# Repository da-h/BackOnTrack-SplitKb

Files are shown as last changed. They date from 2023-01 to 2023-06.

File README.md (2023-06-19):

<h3 align="center">
    <br/>
    <br/><br/>
    Custom Split-Keyboard with 44 keys, 2 trackpads, 2 trackpad-buttons, per-key LED, underglow LED. Supports <a href="https://qmk.fm/">QMK Firmware</a>.
</h3>

<p align="center"> Steps: <a href="#setup">Manufacture</a>, <a href="#installation">Install</a>, <a href="#flashing">Flash</a>, <a href="#assemble">Assemble</a>
</p>

pcb

# Manufacture
(coming soon)

# Install
(coming soon)

# Flash
(coming soon)

# Assemble
(coming soon)

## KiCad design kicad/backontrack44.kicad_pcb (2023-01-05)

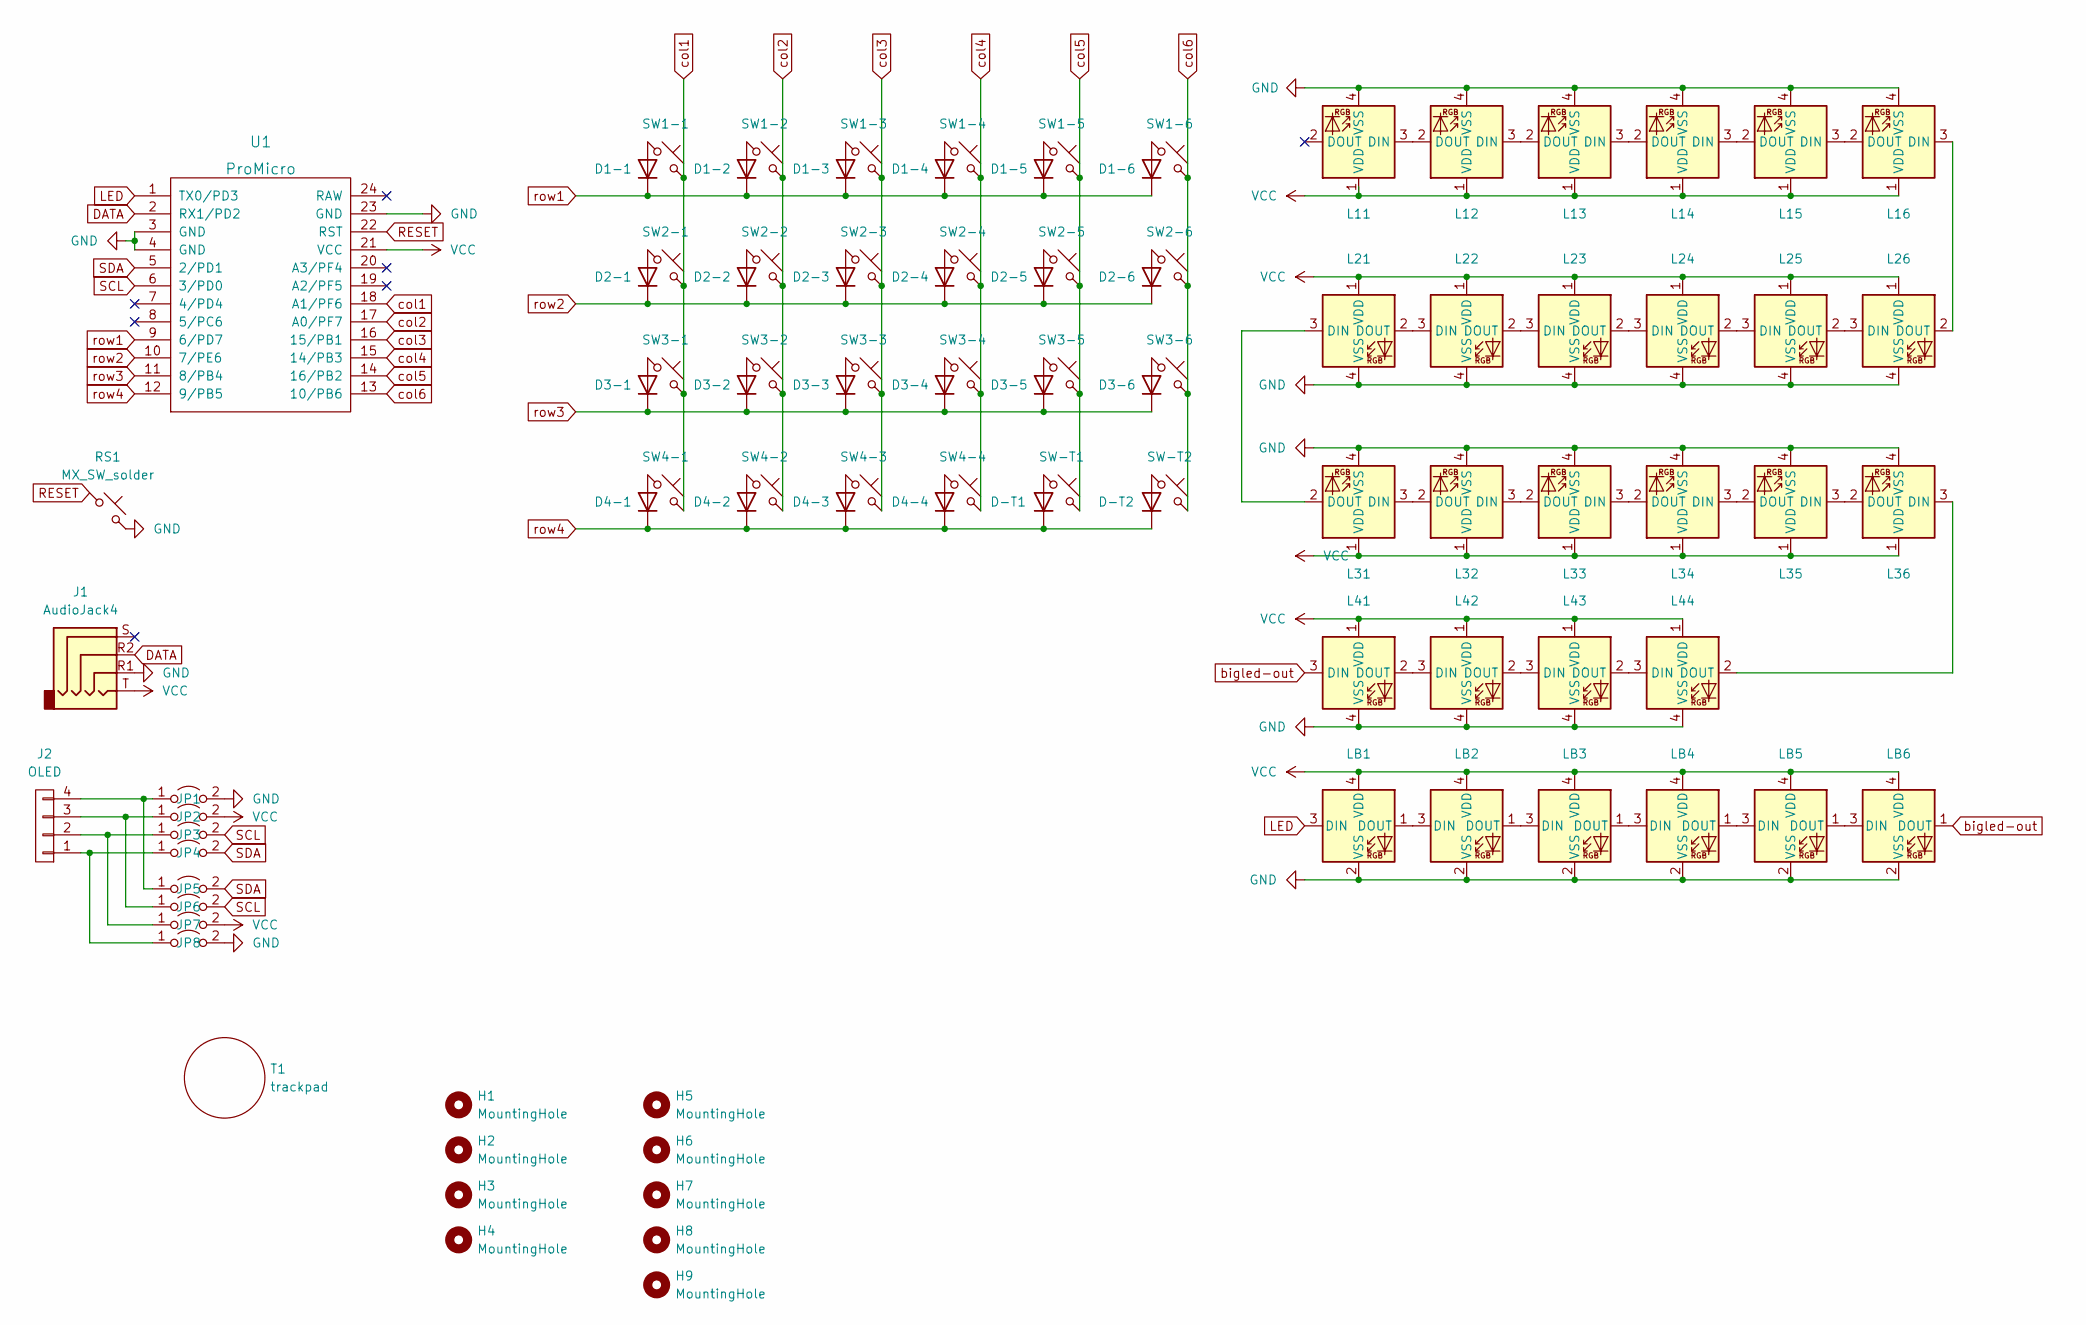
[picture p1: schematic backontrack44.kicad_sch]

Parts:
D1-1, D1-2, D1-3, D1-4, D1-5, D1-6, D2-1, D2-2, D2-3, D2-4, D2-5, D2-6, D3-1, D3-2, D3-3, D3-4, D3-5, D3-6, D4-1, D4-2, D4-3, D4-4: 1N4148W; Diode_SOD123
D-T1, D-T2: 1N4148W; Diode_SOD123
H1, H2, H3, H4: MountingHole; MountingHole_2.2mm_M2_ISO14580_Pad
H5, H6, H7, H8, H9: MountingHole; MountingHole_2.5mm_Pad
J1: AudioJack4; TRRS_JACK_MJ4PP9_Renamed
J2: OLED; OLED_4Pin
JP1, JP2, JP3, JP4, JP5, JP6, JP7, JP8: Jumper_2_Open; Jumper
L11, L12, L13, L14, L15, L16, L31, L32, L33, L34, L35, L36: choc_SK6812MINI-E; LED_choc_6028R_doublesided_rotated
L21, L22, L23, L24, L25, L26, L41, L42, L43, L44: choc_SK6812MINI-E; LED_choc_6028R_doublesided_rotated_twice
LB1, LB2, LB3, LB4, LB5, LB6: SK6812MINI; LED_SK6812MINI_PLCC4_3.5x3.5mm_P1.75mm
RS1: MX_SW_solder; TACT_SWITCH_TVBP06
SW1-1, SW1-2, SW1-3, SW1-4, SW1-5, SW1-6, SW2-1, SW2-2, SW2-3, SW2-4, SW2-5, SW2-6, SW3-1, SW3-2, SW3-3, SW3-4, SW3-5, SW3-6, SW4-2, SW4-3, SW4-4: choc_SW_HS; SW_choc_HS_1u_reversible_rotated
SW4-1: choc_SW_HS; SW_choc_HS_1.5u_reversible_rotated
SW-T1, SW-T2: choc_SW_HS; SW_PUSH_6mm_H5mm
T1: trackpad; trackpad_35mm
U1: ProMicro; ProMicro_rev2

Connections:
DATA: J1.R2, U1.2 (RX1/PD2)
GND: J1.R1, JP1.2 (B), JP8.2 (B), L11.4 (VSS), L12.4 (VSS), L13.4 (VSS), L14.4 (VSS), L15.4 (VSS), L16.4 (VSS), L21.4 (VSS), L22.4 (VSS), L23.4 (VSS), L24.4 (VSS), L25.4 (VSS), L26.4 (VSS), L31.4 (VSS), L32.4 (VSS), L33.4 (VSS), L34.4 (VSS), L35.4 (VSS), L36.4 (VSS), L41.4 (VSS), L42.4 (VSS), L43.4 (VSS), L44.4 (VSS), LB1.2 (VSS), LB2.2 (VSS), LB3.2 (VSS), LB4.2 (VSS), LB5.2 (VSS), LB6.2 (VSS), RS1.2, U1.3 (GND), U1.4 (GND), U1.23 (GND)
LED: LB1.3 (DIN), U1.1 (TX0/PD3)
unnamed: D1-1.2 (A), SW1-1.1
unnamed: D1-2.2 (A), SW1-2.1
unnamed: D1-3.2 (A), SW1-3.1
unnamed: D1-4.2 (A), SW1-4.1
unnamed: D1-5.2 (A), SW1-5.1
unnamed: D1-6.2 (A), SW1-6.1
unnamed: D2-1.2 (A), SW2-1.1
unnamed: D2-2.2 (A), SW2-2.1
unnamed: D2-3.2 (A), SW2-3.1
unnamed: D2-4.2 (A), SW2-4.1
unnamed: D2-5.2 (A), SW2-5.1
unnamed: D2-6.2 (A), SW2-6.1
unnamed: D3-1.2 (A), SW3-1.1
unnamed: D3-2.2 (A), SW3-2.1
unnamed: D3-3.2 (A), SW3-3.1
unnamed: D3-4.2 (A), SW3-4.1
unnamed: D3-5.2 (A), SW3-5.1
unnamed: D3-6.2 (A), SW3-6.1
unnamed: D4-1.2 (A), SW4-1.1
unnamed: D4-2.2 (A), SW4-2.1
unnamed: D4-3.2 (A), SW4-3.1
unnamed: D4-4.2 (A), SW4-4.1
unnamed: D-T1.2 (A), SW-T1.1
unnamed: D-T2.2 (A), SW-T2.1
unnamed: J2.1, JP4.1 (A), JP8.1 (A)
unnamed: J2.2, JP3.1 (A), JP7.1 (A)
unnamed: J2.3, JP2.1 (A), JP6.1 (A)
unnamed: J2.4, JP1.1 (A), JP5.1 (A)
unnamed: L11.3 (DIN), L12.2 (DOUT)
unnamed: L12.3 (DIN), L13.2 (DOUT)
unnamed: L13.3 (DIN), L14.2 (DOUT)
unnamed: L14.3 (DIN), L15.2 (DOUT)
unnamed: L15.3 (DIN), L16.2 (DOUT)
unnamed: L16.3 (DIN), L26.2 (DOUT)
unnamed: L21.2 (DOUT), L22.3 (DIN)
unnamed: L21.3 (DIN), L31.2 (DOUT)
unnamed: L22.2 (DOUT), L23.3 (DIN)
unnamed: L23.2 (DOUT), L24.3 (DIN)
unnamed: L24.2 (DOUT), L25.3 (DIN)
unnamed: L25.2 (DOUT), L26.3 (DIN)
unnamed: L31.3 (DIN), L32.2 (DOUT)
unnamed: L32.3 (DIN), L33.2 (DOUT)
unnamed: L33.3 (DIN), L34.2 (DOUT)
unnamed: L34.3 (DIN), L35.2 (DOUT)
unnamed: L35.3 (DIN), L36.2 (DOUT)
unnamed: L36.3 (DIN), L44.2 (DOUT)
unnamed: L41.2 (DOUT), L42.3 (DIN)
unnamed: L42.2 (DOUT), L43.3 (DIN)
unnamed: L43.2 (DOUT), L44.3 (DIN)
unnamed: LB1.1 (DOUT), LB2.3 (DIN)
unnamed: LB2.1 (DOUT), LB3.3 (DIN)
unnamed: LB3.1 (DOUT), LB4.3 (DIN)
unnamed: LB4.1 (DOUT), LB5.3 (DIN)
unnamed: LB5.1 (DOUT), LB6.3 (DIN)
RESET: RS1.1, U1.22 (RST)
SCL: JP3.2 (B), JP6.2 (B), U1.6 (3/PD0)
SDA: JP4.2 (B), JP5.2 (B), U1.5 (2/PD1)
VCC: J1.T, JP2.2 (B), JP7.2 (B), L11.1 (VDD), L12.1 (VDD), L13.1 (VDD), L14.1 (VDD), L15.1 (VDD), L16.1 (VDD), L21.1 (VDD), L22.1 (VDD), L23.1 (VDD), L24.1 (VDD), L25.1 (VDD), L26.1 (VDD), L31.1 (VDD), L32.1 (VDD), L33.1 (VDD), L34.1 (VDD), L35.1 (VDD), L36.1 (VDD), L41.1 (VDD), L42.1 (VDD), L43.1 (VDD), L44.1 (VDD), LB1.4 (VDD), LB2.4 (VDD), LB3.4 (VDD), LB4.4 (VDD), LB5.4 (VDD), LB6.4 (VDD), U1.21 (VCC)
bigled-out: L41.3 (DIN), LB6.1 (DOUT)
col1: SW1-1.2, SW2-1.2, SW3-1.2, SW4-1.2, U1.18 (A1/PF6)
col2: SW1-2.2, SW2-2.2, SW3-2.2, SW4-2.2, U1.17 (A0/PF7)
col3: SW1-3.2, SW2-3.2, SW3-3.2, SW4-3.2, U1.16 (15/PB1)
col4: SW1-4.2, SW2-4.2, SW3-4.2, SW4-4.2, U1.15 (14/PB3)
col5: SW1-5.2, SW2-5.2, SW3-5.2, SW-T1.2, U1.14 (16/PB2)
col6: SW1-6.2, SW2-6.2, SW3-6.2, SW-T2.2, U1.13 (10/PB6)
row1: D1-1.1 (K), D1-2.1 (K), D1-3.1 (K), D1-4.1 (K), D1-5.1 (K), D1-6.1 (K), U1.9 (6/PD7)
row2: D2-1.1 (K), D2-2.1 (K), D2-3.1 (K), D2-4.1 (K), D2-5.1 (K), D2-6.1 (K), U1.10 (7/PE6)
row3: D3-1.1 (K), D3-2.1 (K), D3-3.1 (K), D3-4.1 (K), D3-5.1 (K), D3-6.1 (K), U1.11 (8/PB4)
row4: D4-1.1 (K), D4-2.1 (K), D4-3.1 (K), D4-4.1 (K), D-T1.1 (K), D-T2.1 (K), U1.12 (9/PB5)

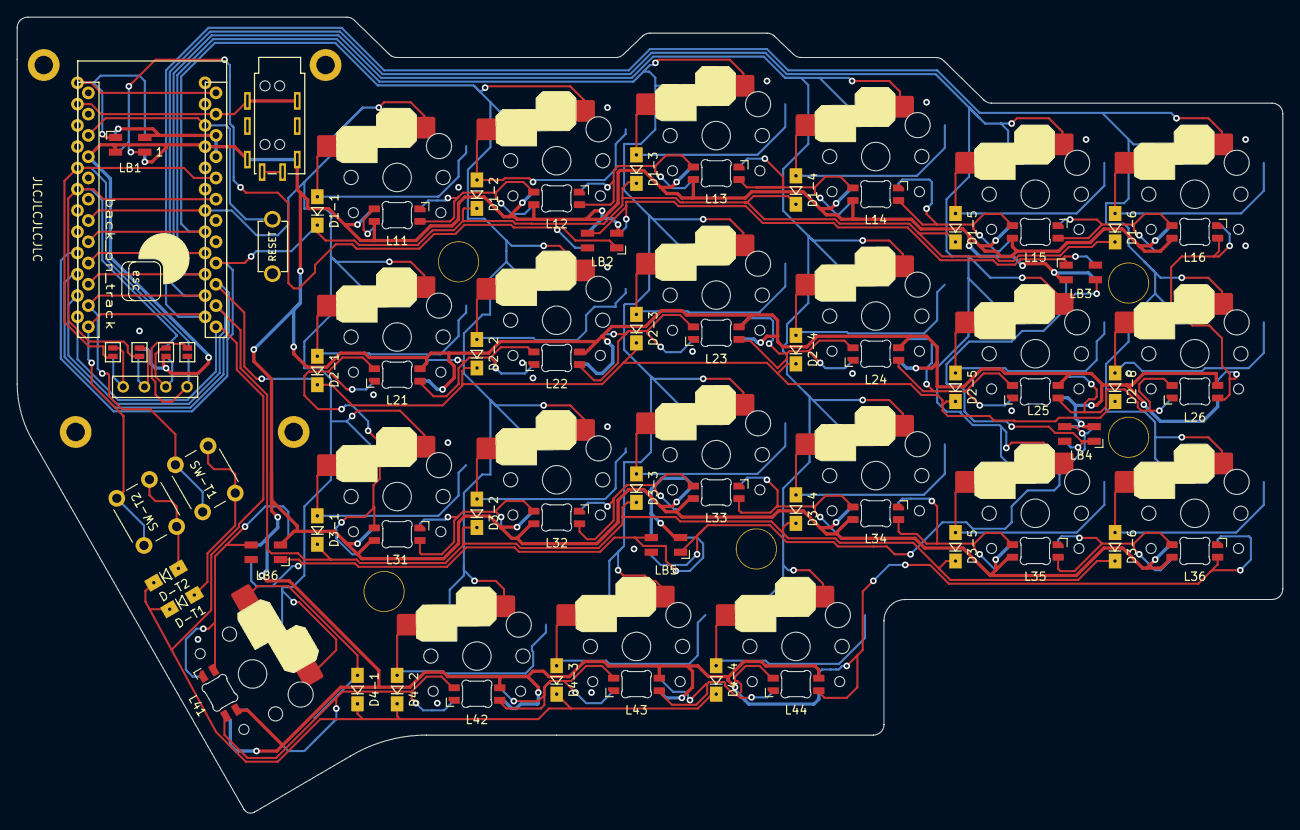
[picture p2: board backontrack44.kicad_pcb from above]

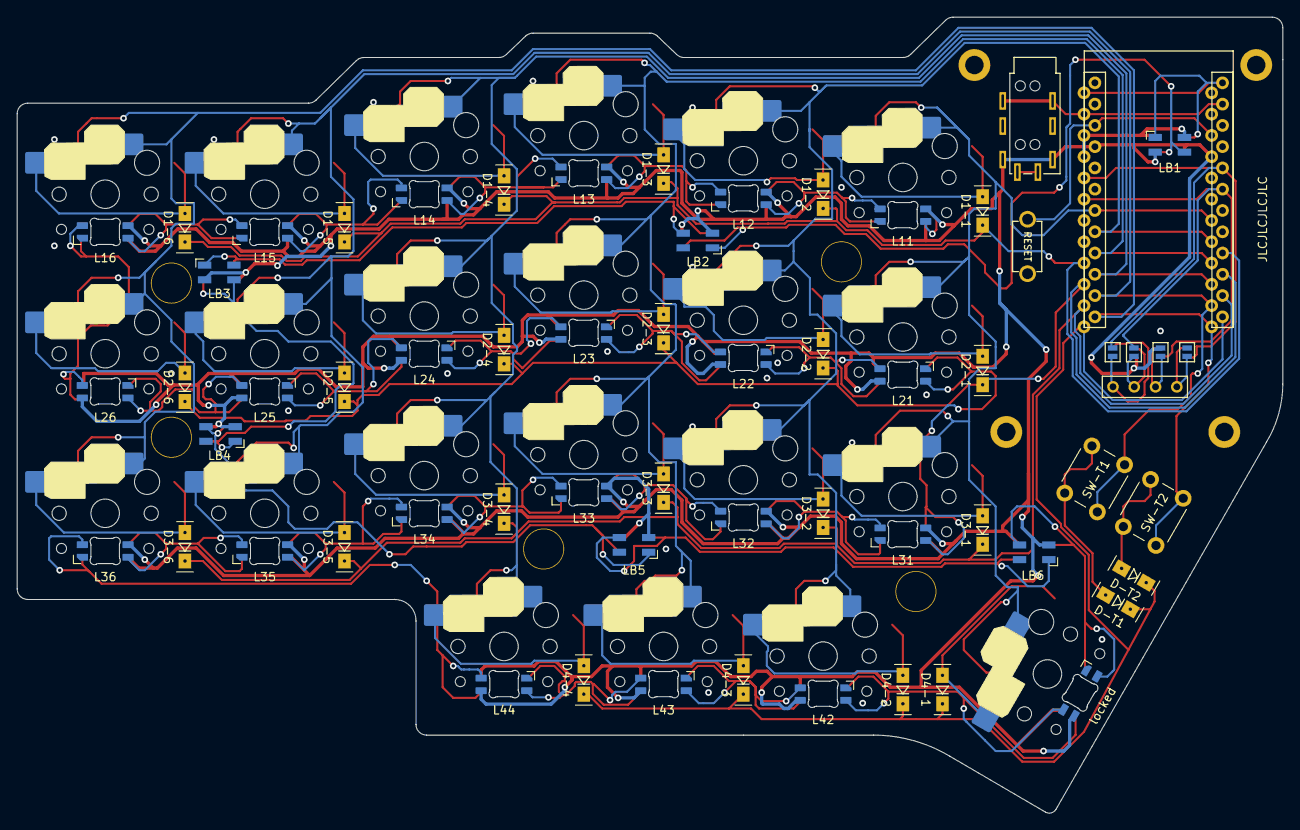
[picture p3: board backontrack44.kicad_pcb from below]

Board: 2 copper layers, 151.1 x 95.0 mm, 100 parts (4 on the bottom side), 72 nets.

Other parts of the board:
JLCJLCJLCJLC: production label
esc: Logo

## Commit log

2023-01-02 added gitignore for kicad projects
2023-01-02 added footprints
2023-01-02 added project files
    [backontrack44.kicad_pcb, backontrack44.kicad_sch]
2023-01-02 better fitting of the board on the right side
    [backontrack44.kicad_pcb]
2023-01-02 fix overlapping errors
    [backontrack44.kicad_pcb]
2023-01-02 fixed many DRC errors
    [backontrack44.kicad_pcb]
2023-01-02 removed col5 and col6 loops
    [backontrack44.kicad_pcb]
2023-01-02 fixed another DRC error
    [backontrack44.kicad_pcb]
2023-01-05 added B-leds to back side as well
    [backontrack44.kicad_pcb]
2023-01-05 added missing "true" connections
    [backontrack44.kicad_pcb]
2023-01-05 fixed some missing GND connections
    [backontrack44.kicad_pcb]
2023-01-05 fixed all missing GND connections
    [backontrack44.kicad_pcb]
2023-01-05 simplified GND connections using VIAs
    [backontrack44.kicad_pcb]
2023-01-05 tighter edge cuts
    [backontrack44.kicad_pcb]
2023-01-05 simplified some connections
    [backontrack44.kicad_pcb]
2023-01-05 added logo
    [backontrack44.kicad_pcb]
2023-01-05 fixed most warnings
    [backontrack44.kicad_pcb]
2023-01-05 fix last silkscreen warning
    [backontrack44.kicad_pcb]
2023-01-05 final save
    [backontrack44.kicad_pcb]
2023-01-05 moved holes away from b-leds
    [backontrack44.kicad_pcb]
2023-06-19 renamed backontrack44-subfolder -> kicad
    [backontrack44.kicad_pcb, backontrack44.kicad_sch]
